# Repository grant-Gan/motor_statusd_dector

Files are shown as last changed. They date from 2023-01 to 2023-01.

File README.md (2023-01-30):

# 电机健康状态检测系统

该项目为基于ESP32 Arduino框架开发, ESP32通过热电偶与振动传感器检测电机四个点的震动状态以及温度判数据; 而后将数据上传致One Net云平台, 进行数据可视化显示与报警阈值的动态设置.

硬件连接图:
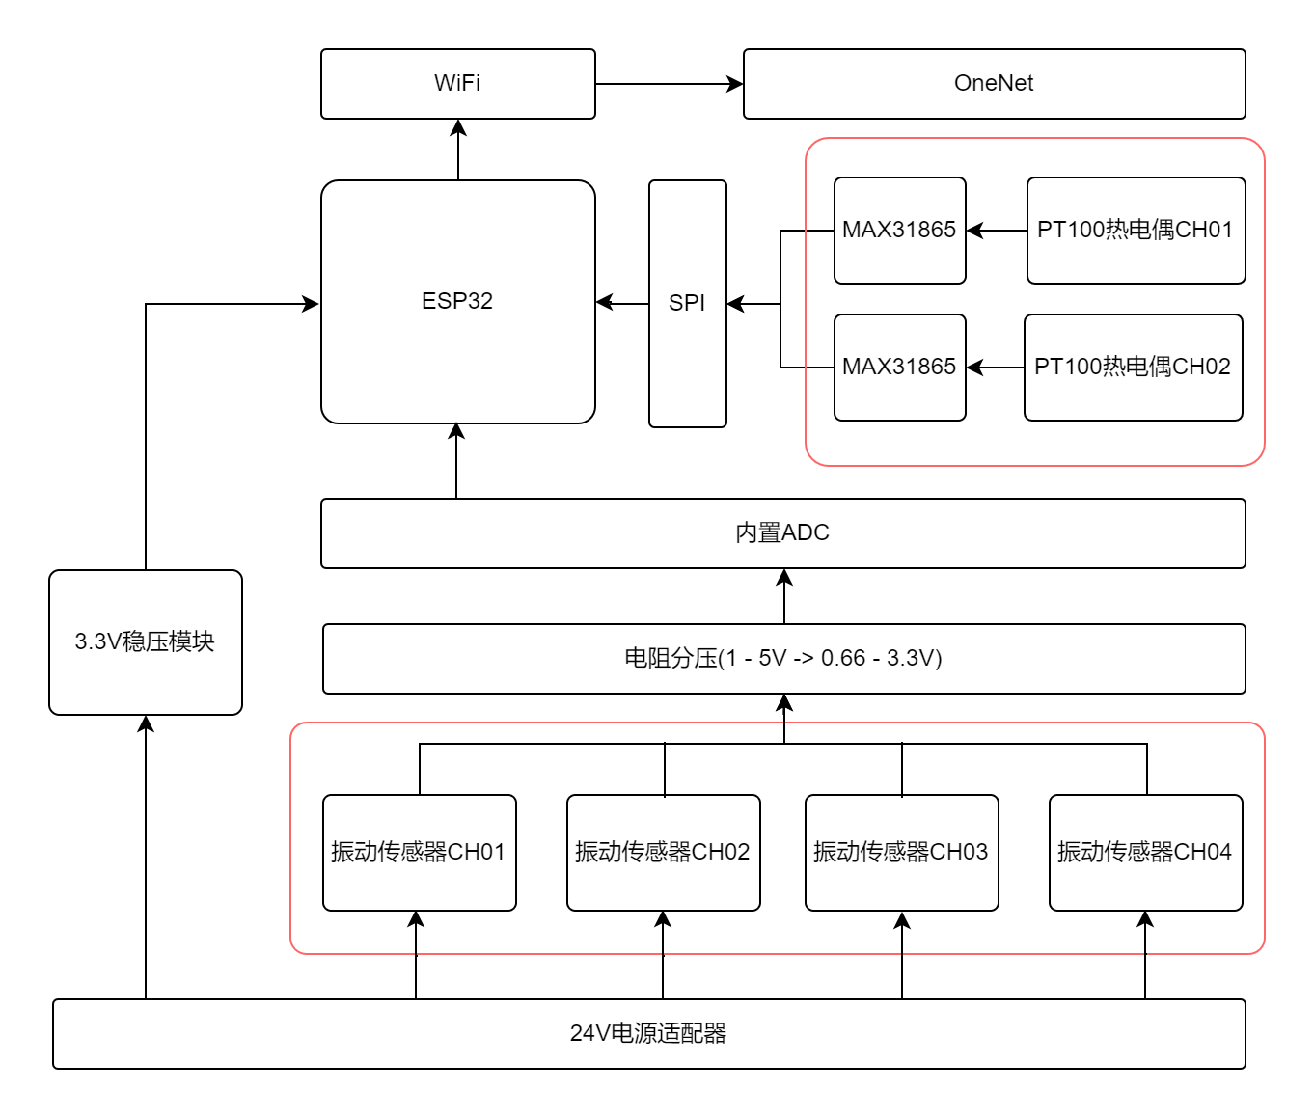
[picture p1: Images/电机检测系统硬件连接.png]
系统框架连接图


程序框图:
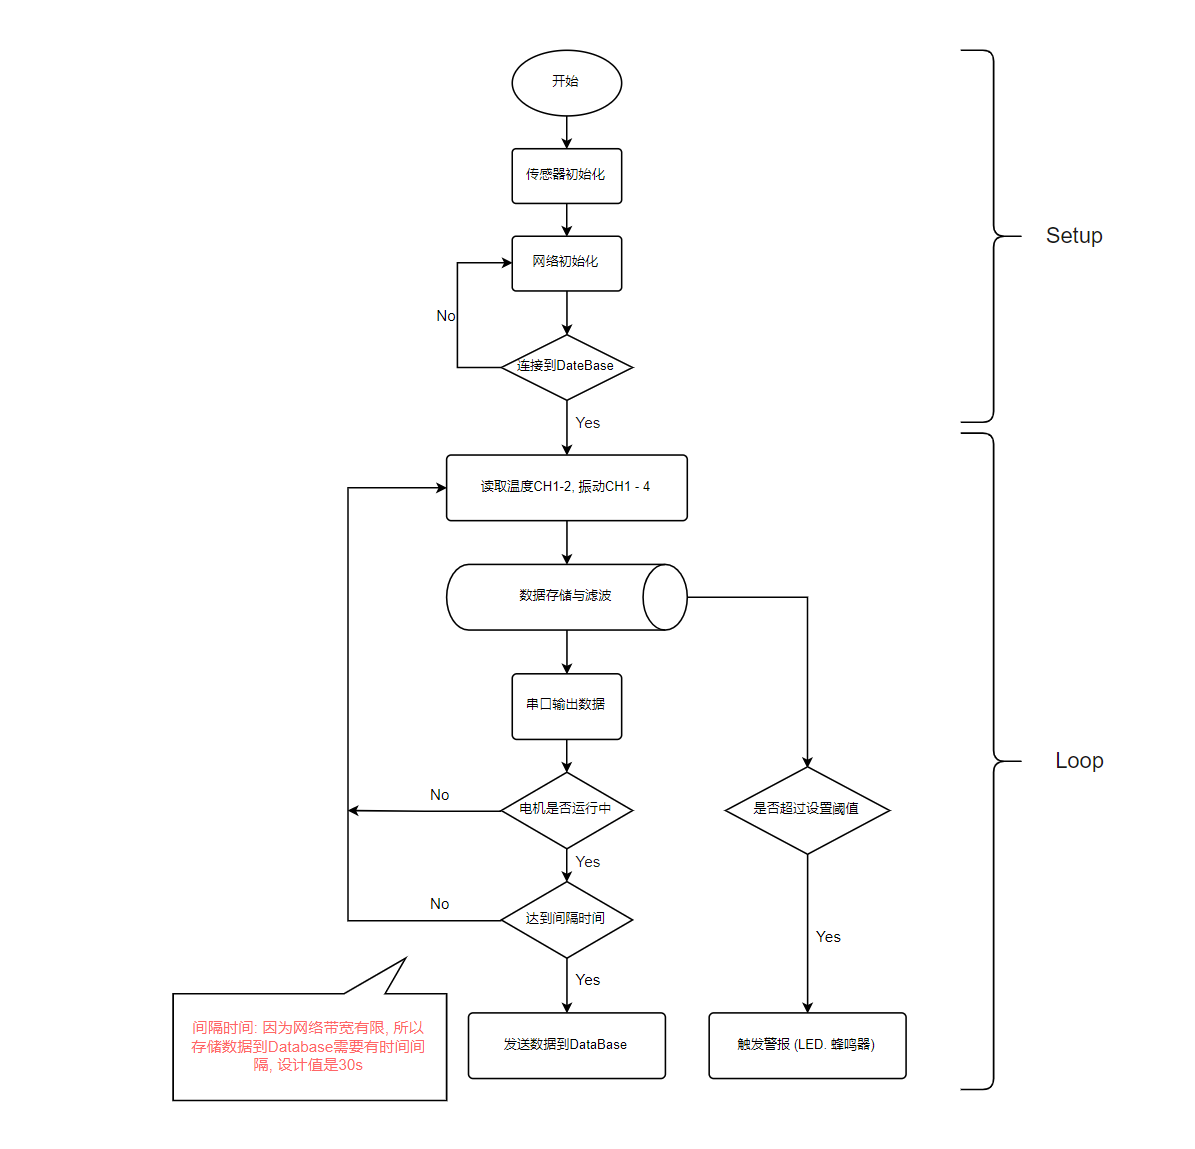
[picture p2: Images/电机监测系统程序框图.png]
程序框图


One Net数据可视化:
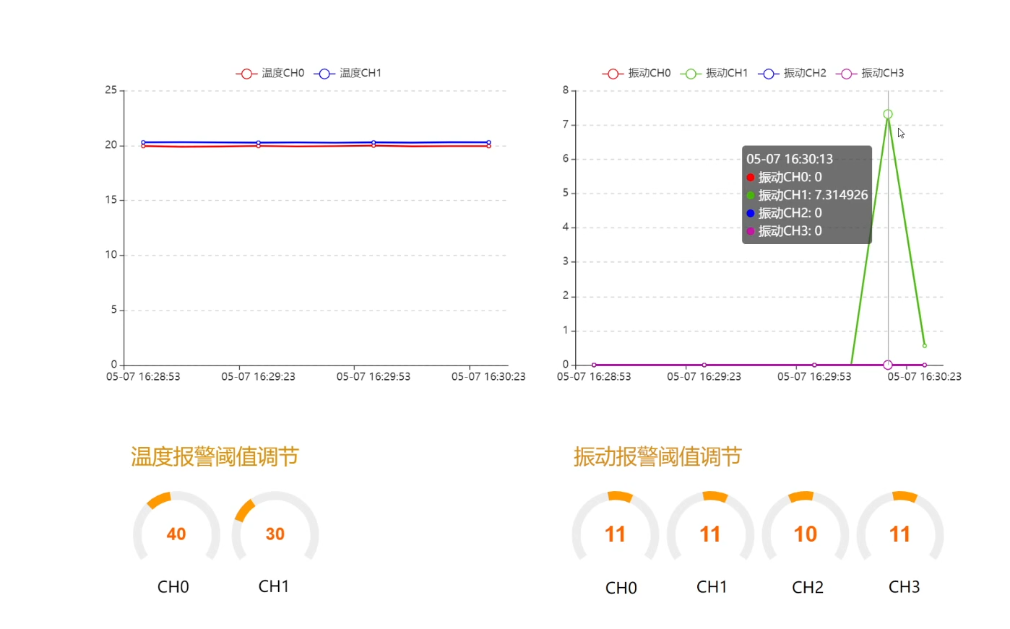
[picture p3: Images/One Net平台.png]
One Net平台预览


PCB 3D模型预览:
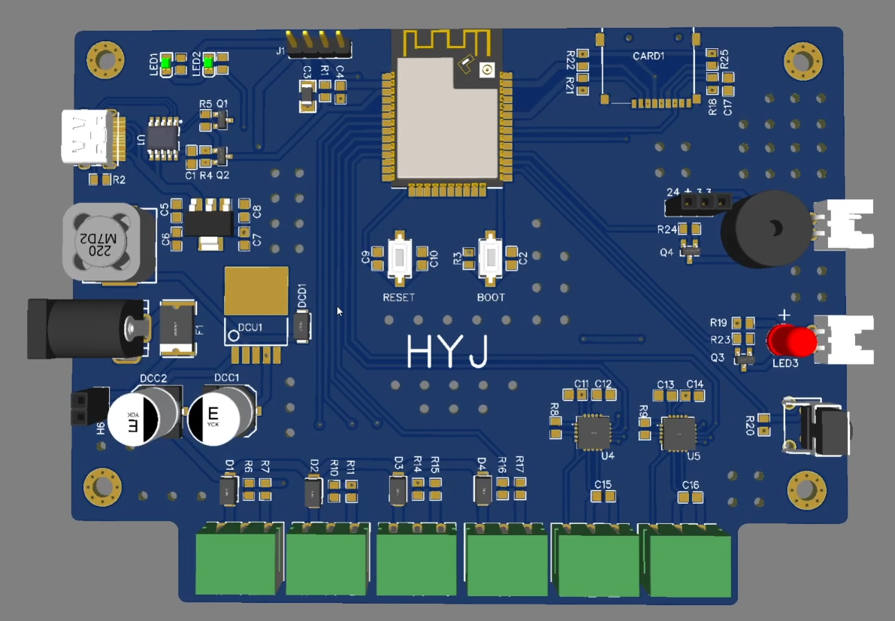
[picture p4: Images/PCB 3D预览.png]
PCB 3D模型预览


最终实物:
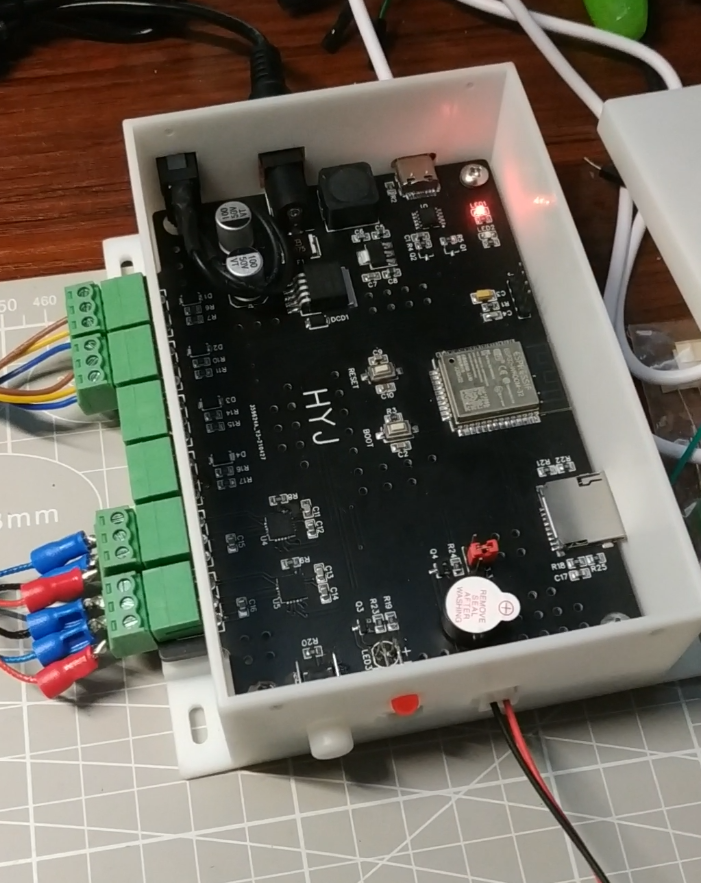
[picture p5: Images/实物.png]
最终实物


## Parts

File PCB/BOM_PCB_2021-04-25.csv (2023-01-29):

ID | Designator | Name | Footprint | Quantity | Manufacturer Part | Manufacturer | Supplier | Supplier Part | Price | JLCPCB SMD | Paste Type | EasyEDA
1 | BOOT,RESET | BOOT | KEY-SMD_2P-L6.2-W3.6-LS8.0 | 2 | K2-1107ST-A4SW-06 |  | LCSC | C118141 | 0.0423
2 | C1,C5,C7,C17 | 104 | C0805 | 4 |  |  | LCSC
3 | C3 | 100uF | 1206 | 1
4 | C6,C8 | 10uF | C0805 | 2 |  |  | LCSC
5 | C9 | 105 | C0805 | 1
6 | C2,C4,C10,C11,C12,C13,C14,C15,C16 | 104 | C0805 | 9
7 | CARD1 | TF-01A | TF-SMD_TF-01A | 1 | TF-01A | HRO | LCSC | C91145 | 1.1823
8 | CN1 | YKYB40-CH00 | CONN-TH_3P-P3.81_KF2EDGR-3.81-3P | 1 | KF2EDGR-3.81-3P | Cixi Kefa Elec | LCSC | C441183 | 0.318802 |  | expand
9 | CN2 | YKYB40-CH01 | CONN-TH_3P-P3.81_KF2EDGR-3.81-3P | 1 | KF2EDGR-3.81-3P | Cixi Kefa Elec | LCSC | C441183 | 0.318802 |  | expand
10 | CN3 | PT100-CH0 | CONN-TH_3P-P3.81_KF2EDGR-3.81-3P | 1 | KF2EDGR-3.81-3P | Cixi Kefa Elec | LCSC | C441183 | 0.318802 |  | expand
11 | CN4 | PT100-CH1 | CONN-TH_3P-P3.81_KF2EDGR-3.81-3P | 1 | KF2EDGR-3.81-3P | Cixi Kefa Elec | LCSC | C441183 | 0.318802 |  | expand
12 | CN5 | YKYB40-CH02 | CONN-TH_3P-P3.81_KF2EDGR-3.81-3P | 1 | KF2EDGR-3.81-3P | Cixi Kefa Elec | LCSC | C441183 | 0.318802 |  | expand
13 | CN6 | YKYB40-CH03 | CONN-TH_3P-P3.81_KF2EDGR-3.81-3P | 1 | KF2EDGR-3.81-3P | Cixi Kefa Elec | LCSC | C441183 | 0.318802 |  | expand
14 | D1,D2,D3,D4 | SS34 | SMAF | 4 | 1N4007W | BLUE ROCKET | LCSC | C328592 | 0.04999
15 | DC1 | DC005-2.0MM | DC-IN-TH_DC005 | 1 | DC005-2.0MM | SOFNG | LCSC | C111567 | 1
16 | DCC1,DCC2 | 100uF | SMD-8*10.5 | 2
17 | DCD1 | SS54 | SMAF | 1
18 | DCL1 | 330 | IND-SMD_L12.0-W12.0_CDRH127NP | 1
19 | DCU1 | LM2596-3.3 | LM2596 | 1 | ?
20 | F1 | TLC-LSMD050/50 | F2920 | 1 | TLC-LSMD050/50 | TLC Electronic | LCSC | C506870 | 0.562325
21 | H1,H2,H3,H4 | Hole-3mm-JK 孔 | HOLE-3MM | 4 | Hole-3mm
22 | H5 | HDR-F-2.54_1x3 | HDR-F-2.54_1X3 | 1 |  |  | LCSC | C146690 | 0.278
23 | H6 | PowerSwitch | HDR-F-2.54_1X2 | 1 |  |  | LCSC | C49661 | 0.162
24 | H7 | BUZZER | XH2.54-2AW | 1 |  |  | LCSC | C49661 | 0.162
25 | H8 | WAR_LED | XH2.54-2AW | 1 |  |  | LCSC | C49661 | 0.162
26 | J1 | 串口 | HDR-M-2.54_1X4 | 1 |  |  | LCSC | C124378 | 0.143949
27 | LED1,LED2 | LED-0805_R | LED0805-RD | 2 | 19-217/R6C-AL1M2VY/3T | EVERLIGHT(台湾亿光) | LCSC | C72044 | 0.081951
28 | LED3 | LED-TH-5mm_R | LED-TH_BD5.0_RED | 1 | 333-2SURD/S530-A3 | EVERLIGHT(台湾亿光) | LCSC | C87271 | 0.191428
29 | Q1,Q2 | S8050 | SOT-23-3_L2.9-W1.3-P1.90-LS2.4-BR | 2 | S8050 | FUXINSEMI | LCSC | C908252 | 0.058733 | Yes
30 | Q3,Q4 | 2N5551 | SOT-23-3_L2.9-W1.3-P1.90-LS2.4-TR | 2 | 2n3904S-RTK/PS | KEC | LCSC | C18536 | 0.071167 |  | SOT-23
31 | R1,R3 | 4.7k | R0805 | 2
32 | R2 | 5.1K | R0805 | 1 | AF0603FR-0710KL | YAGEO | LCSC | C144081 | 0.045
33 | R4,R5,R18,R21,R22,R25 | 10K | R0805 | 6 | TC0325F1002T5E | UniOhm | LCSC | C128781 | 0.0268 | Yes
34 | R6,R10,R11,R14,R15,R16,R17,R20 | 10k | R0805 | 8
35 | R7 | 10k 1% | R0805 | 1
36 | R8,R9 | 430 | R0805 | 2 | RMC06034.7K1%N | Tyohm | LCSC | C269713 | 0.015397
37 | R12,R13,R19,R23,R24 | 1k | R0805 | 5
38 | SG1 | BUZZER | BUZZER-12MM-NS | 1
39 | SW1 | 卧式按键开关 | 轻触按键开关卧式带支架 | 1
40 | U1 | CH340K | ESOP-10_L4.9-W3.9-P1.00-LS6.2-BL-EP | 1 | CH340K | WCH(Jiangsu Qin Heng) | LCSC | C968586 | 3.28
41 | U2 | AMS1117-3.3 | SOT-223 | 1 | AMS1117-3.3 | AMS | EasyEDA | C6186 | 0.728 |  |  | C6186
42 | U3 | ESP32-S | WIRELM-SMD_ESP32-S | 1 | ESP32-S | Ai-Thinker | LCSC | C277944 | 25.9
43 | U4,U5 | MAX31865ATP+ | QFN-20_L5.0-W5.0-P0.65-BL-EP | 2 | MAX31865ATP+ | Maxim Integrated | LCSC | C404011 | 36.7 |  | expand
44 | USB1 | TYPE C 16PIN | TYPE C 16P | 1 | TYPE-C16PIN | SHOU HAN | LCSC | C393939 | 0.78

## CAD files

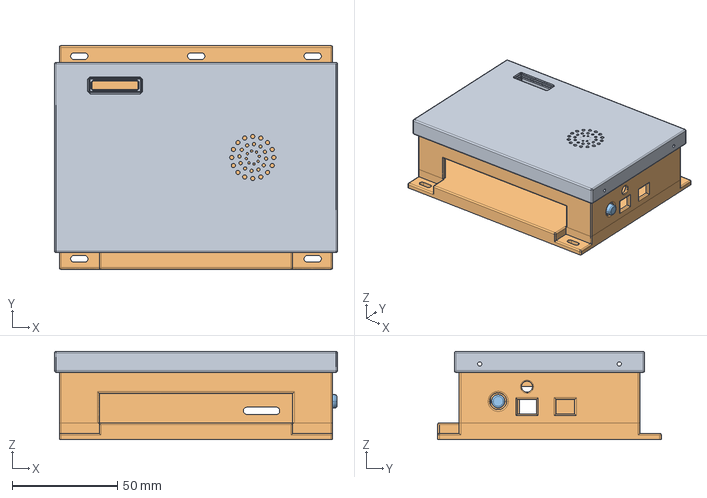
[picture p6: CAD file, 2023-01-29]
3DModel/3D模型.stp
134.6 x 106.4 x 42.0 mm

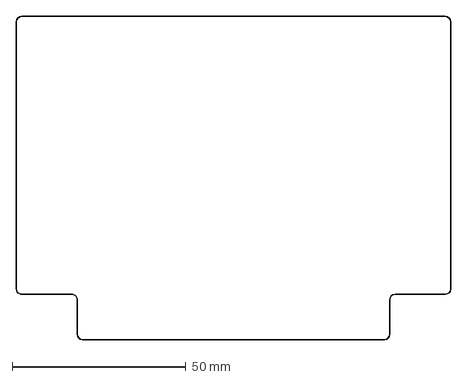
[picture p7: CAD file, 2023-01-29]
3DModel/pcb边缘.dxf
125.0 x 93.0 mm

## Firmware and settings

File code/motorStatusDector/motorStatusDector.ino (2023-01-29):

/*
  程序目的 : 实现传感器数据读取、超阈值监测、上传数据到云平台
  一、硬件材料
  1. 振动传感器 * 4 接在主板接口左侧四路接口上
  2. 温度传感器 * 2 接在主板接口右侧两路接口上
  3. 24v电源, 注意24V电源与USB接口不可同时供电
  4. SD卡
  二、预期效果
  1. 状态指示灯会先亮起, 大约七八秒以后熄灭, 之后每十秒闪烁一次
  2. 数据会被写入到SD卡
  3. 数据会被上传到OneNet平台
  4. 会从OneNet平台读取最新的阈值
  5. 当传感器的采集到的数据超过阈值以后, 会报警(红灯亮+蜂鸣器响)

  更新信息:
    更新日期: 2021/5/12/17:13
    更新内容:
      - 增加只有在电机运行时才会自动进行SD卡及oneNet端数据上传功能
      - 增加motor::getRunningStatus()方法

    更新日期: 2021/5/14/22:56
    更新内容:
      - 在数据写入和上传之前更新一次传感器数据
      - 将阈值一起写入CSV文件

    更新日期: 2021/5/18/18:46
    更新内容:
      - 修复超过阈值时写入表格数据错误问题   
*/

#include <Arduino.h>
#include <string>
#include <Adafruit_MAX31865.h>
#include <WiFi.h>
#include <HTTPClient.h>
#include <ArduinoJson.h>
#include <FS.h>
#include <SD.h>
#include <SPI.h>
#include <time.h>
#include <Ticker.h>

//定义温度传感器通道数量
#define TEMP_CH 2
//定义振动传感器通道数量
#define VIBRA_CH 4
//定义SD卡CS引脚
#define SDCARD_CS_PIN 21
//定义max31865传感器CS引脚
#define TEMP_CH0_PIN 26
#define TEMP_CH1_PIN 25
//定义振动传感器模拟输出引脚
#define VIBRA_CH0_PIN 34
#define VIBRA_CH1_PIN 35
#define VIBRA_CH2_PIN 32
#define VIBRA_CH3_PIN 33
//报警器引脚
#define WARNNER_LED_PIN 16
#define WARNNER_BUZZER_PIN 17
#define WARNNER_INTERRUPT_PIN 4
//状态指示灯引脚
#define STATUS_LED 2
//定义平均值滤波中温度的采样次数
//因考虑到max31865传输数字信号, 故该值可较小
#define TEMP_SAMP_COUNT 5

//定义振动信号滤波采样次数
//因该信号为模拟量传输, 故该值可较大
#define VIBRA_SAMP_COUNT 51

const char* SSID = "TEST";
const char* PWD = "20201234";

const String api_key = "ZH8lES5PNdvqTcO82bbYuQ6AHBU=";
const String device_id = "716081919";


class TempSensor {

  protected:
    Adafruit_MAX31865 thermo;
    // Rref电阻阻值选择, PT100 -> 430 PT1000 -> 4300
    const float RREF = 430.0;
    // The 'nominal' 0-degrees-C resistance of the sensor
    // 100.0 for PT100, 1000.0 for PT1000
    const float RNOMINAL = 100.0;

  public:

    TempSensor(int8_t spi_cs) : thermo(spi_cs) {
      //传递spi_cs值, 并且设置PT100为三线制
      thermo.begin(MAX31865_3WIRE);
    }

    float readData() {
      float temperture = thermo.temperature(RNOMINAL, RREF);
      //Serial.print("temperature = \t"); Serial.println(temperture);

      return temperture;
    }

    // 检查检测温度是否有错误
    // 错误返回true, 否则返回flase
    bool checkFault() {
      uint8_t fault = thermo.readFault();

      if (fault) {
        Serial.print("Fault 0x"); Serial.println(fault, HEX);
        if (fault & MAX31865_FAULT_HIGHTHRESH) {
          Serial.println("RTD High Threshold");
        }
        if (fault & MAX31865_FAULT_LOWTHRESH) {
          Serial.println("RTD Low Threshold");
        }
        if (fault & MAX31865_FAULT_REFINLOW) {
          Serial.println("REFIN- > 0.85 x Bias");
        }
        if (fault & MAX31865_FAULT_REFINHIGH) {
          Serial.println("REFIN- < 0.85 x Bias - FORCE- open");
        }
        if (fault & MAX31865_FAULT_RTDINLOW) {
          Serial.println("RTDIN- < 0.85 x Bias - FORCE- open");
        }
        if (fault & MAX31865_FAULT_OVUV) {
          Serial.println("Under/Over voltage");
        }
        thermo.clearFault();
        return true;
      }
      else {
        return false;
      }
    }

};

class Motor {

  public:
    enum SenorChEnum
    {
      CH0 = 0,
      CH1,
      CH2,
      CH3
    };

    //温度和振动烈度的报警阈值, 为方便访问, 使用 public
    uint16_t tempThresholdCh[TEMP_CH] = { 100 };
    uint16_t vibraThresholdCh[VIBRA_CH] = { 10 };

    bool tempExceedFlagCh[TEMP_CH] = { false };
    bool vibraExceedFlagCh[VIBRA_CH] = { false };
  protected:

    TempSensor pt100Ch[TEMP_CH] = {
      TempSensor(TEMP_CH0_PIN),
      TempSensor(TEMP_CH1_PIN)
    };
    float tempCh[TEMP_CH] = { 0.0 };		//电机温度两通道
    float vibraCh[VIBRA_CH] = { 0.0 };		//电机振动烈度四通道
    bool runningStatus = false;
  public:
    //检查电机的运行状态, 运行中返回false, 否则返回true;
    bool getRunningStatus() {
      if ( (vibraCh[0] + vibraCh[1] + vibraCh[2] + vibraCh[3]) <= 0.01) {
        runningStatus = false;
        return false;
      }
      else {
        runningStatus = true;
        return true;
      }
    }
    //检查温度和振动的每一个通道, 如果有超过值, 则vibraExceedFlagChx设为true
    //并且方法返回true
    bool checkSenorExceed() {

      bool exceed = false;

      for (uint16_t i = 0; i < TEMP_CH; i++) {
        if (tempCh[i] >= tempThresholdCh[i]) {
          exceed = true;
          tempExceedFlagCh[i] = true;
        }
        else
          tempExceedFlagCh[i] = false;
      }
      for (uint16_t i = 0; i < VIBRA_CH; i++) {
        if (vibraCh[i] >= vibraThresholdCh[i]) {
          exceed = true;
          vibraExceedFlagCh[i] = true;
        }
        else
          vibraExceedFlagCh[i] = false;
      }
      return exceed;
    }

    //获取单通道温度值, 注意:该函数并不会更新数据, 只是单纯地返回上一次的读取值
    float getTempChx(SenorChEnum chx) {
      switch (chx)
      {
        case CH0 : return tempCh[CH0]; break;
        case CH1 : return tempCh[CH1]; break;
        default:
          Serial.println("Invalid channal ! ");
          break;
      }
    }

    //获取单通道振动值, 注意:该函数并不会更新数据, 只是单纯地返回上一次的读取值
    float getVibraChx(SenorChEnum chx) {
      switch (chx)
      {
        case CH0: return vibraCh[CH0]; break;
        case CH1: return vibraCh[CH1]; break;
        case CH2: return vibraCh[CH2]; break;
        case CH3: return vibraCh[CH3]; break;
        default:
          Serial.println("Invalid channal ! ");
          break;
      }
    }
    //获取温度传感器的值 存储在tempBuffer里面
    //参数: tempBuffer数组变量, 长度必须大于温度传感器通道数
    //    array_size数组长度
    bool getTemp(float tempBuffer[], uint16_t array_size) {
      if (array_size < TEMP_CH) {
        Serial.print("temp buffer size so short");
        return false;
      }
      if (!updateTemp()) {
        Serial.print("get temperture error!");
        return false;
      }
      tempBuffer[0] = this->tempCh[0];
      tempBuffer[1] = this->tempCh[1];
      return true;
    }
    //获取振动传感器的值 存储在vibraBuffer里面
    //参数: vibraBuffer数组变量, 长度必须大于温度传感器通道数
    //    array_size数组长度
    bool getVibra(float vibraBuffer[], uint16_t array_size) {
      if (array_size < VIBRA_CH) {
        Serial.print("vibra Buffer size so short");
        return false;
      }

      if (!updateVibra()) {
        Serial.print("get vibration error!");
        return false;
      }
      for (uint8_t i = 0; i < VIBRA_CH; i++)
        vibraBuffer[i] = vibraCh[i];

      return true;
    }

    //更新振动传感器数据
    //
    bool updateVibra() {

      //定义二位数组用于存放ADC采集到的振动传感器电压
      uint16_t vibra_voltage[VIBRA_CH][VIBRA_SAMP_COUNT] = { 0 };
      //定义单通道数组, 用于存放振动传感器经过滤波后的值
      uint16_t vibra_vol_filter[VIBRA_CH] = { 0 };

      for (uint8_t i = 0; i < VIBRA_SAMP_COUNT; i++) {
        vibra_voltage[0][i] = analogRead(VIBRA_CH0_PIN);
        vibra_voltage[1][i] = analogRead(VIBRA_CH1_PIN);
        vibra_voltage[2][i] = analogRead(VIBRA_CH2_PIN);
        vibra_voltage[3][i] = analogRead(VIBRA_CH3_PIN);
        delay(1);
      }

      for (uint8_t i = 0; i < VIBRA_CH; i++) {

        //设置数据上下限, 这里的448 和2947 为仪表测量值, 不可变动
        limiterMinMax(vibra_voltage[i], VIBRA_SAMP_COUNT, 448, 2947);
        //对采样数据进行中位值滤波
        filterMedian(vibra_vol_filter[i], vibra_voltage[i], VIBRA_SAMP_COUNT);
        //通过公式将电压信号转换为振动信号, 结果存储在vibraCh[x]数组里面
        convertVibraFromVoltage(vibraCh[i], vibra_vol_filter[i]);
        //2.5V -> 2946.41875->2947
        //1v -> 1073.375 -> 1073
        //0.5V -> 448.2582 -> 448

      }
      return true;
    }
    //更新温度数据
    //成功返回 true; 失败返回false
    bool updateTemp() {
      float temp_ch0_buffer[TEMP_SAMP_COUNT] = { 0.0 };
      float temp_ch1_buffer[TEMP_SAMP_COUNT] = { 0.0 };

      uint8_t count = 0;    //采样次数
      unsigned long startTime = millis();
      while (count < TEMP_SAMP_COUNT) {
        //while循环超时检测
        if (millis() - startTime >= 1000) {
          Serial.print("get temperture timeout");
          return false;
        }
        //max31865最大采样间隔时间为21ms, 这里取采样间隔25ms
        if (millis() - startTime >= 25) {
          startTime = millis();
          temp_ch0_buffer[count] = pt100Ch[0].readData();
          temp_ch1_buffer[count] = pt100Ch[1].readData();

          if (pt100Ch[0].checkFault() || pt100Ch[1].checkFault())
            continue;
          else
            count += 1;
        }

      }
      //将temp_buffer里的数据经过平均值滤波以后传入到tempCh[0/1];
      filterAvarge(tempCh[0], temp_ch0_buffer, TEMP_SAMP_COUNT);
      filterAvarge(tempCh[1], temp_ch1_buffer, TEMP_SAMP_COUNT);
      return true;
    }

  private:
    //将振动传感器的电压信号转化为振动信号
    void convertVibraFromVoltage(float& target, const uint16_t& source) {
      //(x - in_min) * (out_max - out_min) / (in_max - in_min) + out_min;
      //将电压信号有效值进行线性缩放至0-20mm/s的范围, 这里的数值为测量值或给定值
      //不可以进行更改, 运算过程参考arduino库的map函数
      target = (source - 448.0) * (20.0 - 0.0) / (2947.0 - 448.0) + 0.0;

    }

    //平均值滤波, 针对温度
    void filterAvarge( float& target, const float source[], uint16_t array_size) {
      float filter_sum = 0;

      for ( uint8_t i = 0; i < array_size; i++) {
        filter_sum += source[i];
      }
      target = filter_sum / array_size;
    }

    //数值限幅器
    void limiterMinMax(uint16_t source[], uint16_t arraySize, uint16_t minVaule, uint16_t maxVaule) {

      for (uint16_t i = 0; i < arraySize; i++) {
        if (source[i] < minVaule)
          source[i] = minVaule;
        else if (source[i] > maxVaule)
          source[i] = maxVaule;
        else
          continue;
      }
    }

    //中位值滤波, 针对振动
    void filterMedian(uint16_t& target, uint16_t source[], uint16_t arraySize) {
      uint8_t i, j;
      uint16_t filterTemp;

      // 采样值从小到大排列（冒泡法）
      for (j = 0; j < arraySize - 1; j++) {
        for (i = 0; i < arraySize - 1 - j; i++) {
          if (source[i] > source[i + 1]) {
            filterTemp = source[i];
            source[i] = source[i + 1];
            source[i + 1] = filterTemp;
          }
        }
      }
      //返回中间值
      target = source[(arraySize - 1) / 2];
    }

};

//定义OneNet对象, 对上传数据和 下载数据进行操作
//依赖库为<arduinoJson>
class OneNet {

  protected:
    String apiKey;
    String deviceId;
    String apiUrl = "http://api.heclouds.com/devices/" + deviceId;

  public:
    OneNet(String devId, String aKey) :
      deviceId(devId),
      apiKey(aKey) {}
    //从服务器获取数据, 并将结果更新到Motor对象里
    //主要是用户设定的传感器报警阈值
    void getDataFromServer(Motor& motor) {
      if (WiFi.status() == WL_CONNECTED) {

        HTTPClient http;
        String postUrl = apiUrl + "/datastreams";
        String response;

        http.begin(postUrl);
        http.addHeader("api-key", apiKey);
        http.addHeader("Connection", "close");
        http.addHeader("Content-Type", "application/json");

        int httpResponseCode = http.GET();
        if (httpResponseCode > 0) {

          response = http.getString();

          Serial.println(httpResponseCode);
          //Serial.println(response);
        }
        else
          Serial.println("Error occurred while sending HTTP GET");

        StaticJsonDocument<2048> doc;

        ArduinoJson::deserializeJson(doc, response);
        JsonObject obj = doc.as<JsonObject>();

        uint16_t responeJsonCode = obj["errno"];

        if (responeJsonCode == 0) {
          //此处数字根据服务器传回的Json文件更改的数组顺序, 不可修改
          motor.vibraThresholdCh[3] = obj["data"][3]["current_value"];
          motor.vibraThresholdCh[2] = obj["data"][2]["current_value"];
          motor.vibraThresholdCh[0] = obj["data"][5]["current_value"];
          motor.vibraThresholdCh[1] = obj["data"][0]["current_value"];
          //Serial.println("Vibra threshold is : ");
          //Serial.print("\tch0 "); Serial.print(motor.vibraThresholdCh[0]);
          //Serial.print("\tch1 "); Serial.print(motor.vibraThresholdCh[1]);
          //Serial.print("\tch2 "); Serial.print(motor.vibraThresholdCh[2]);
          //Serial.println("\tch3 "); Serial.print(motor.vibraThresholdCh[3]);

          motor.tempThresholdCh[0] = obj["data"][1]["current_value"];
          motor.tempThresholdCh[1] = obj["data"][4]["current_value"];
          //Serial.println("Temp threshold is : ");
          //Serial.print("\tch0 "); Serial.print(motor.tempThresholdCh[0]);
          //Serial.println("\tch1 "); Serial.print(motor.tempThresholdCh[1]);
        }
        else
          Serial.println("Json get error!");

        http.end();

      }
    }
    //传递motor对象的数据到服务器端, 主要是温度和振动传感器的数字, 传递文件为Json文件
    void postDataToServer(Motor& motor) {

      if (WiFi.status() == WL_CONNECTED) {

        HTTPClient http;

        String jsonOutput;
        String postUrl = apiUrl + "/datapoints";

        float tempBuffer[TEMP_CH] = { 0.0 };
        float vibraBuffer[VIBRA_CH] = { 0.0 };

        motor.getTemp(tempBuffer, TEMP_CH);
        motor.getVibra(vibraBuffer, VIBRA_CH);

        //创建静态Json文档, 这里的384是通过软件计算得到的缓存大小, 不可以任意更改
        StaticJsonDocument<512> doc;

        JsonArray datastreams = doc.createNestedArray("datastreams");

        JsonObject datastreams_0 = datastreams.createNestedObject();
        datastreams_0["id"] = "motorTemp";

        JsonObject datastreams_0_datapoints_0_value = datastreams_0["datapoints"][0].createNestedObject("value");
        datastreams_0_datapoints_0_value["CH0"] = tempBuffer[0];
        datastreams_0_datapoints_0_value["CH1"] = tempBuffer[1];

        JsonObject datastreams_1 = datastreams.createNestedObject();
        datastreams_1["id"] = "motorVibra";

        JsonObject datastreams_1_datapoints_0_value = datastreams_1["datapoints"][0].createNestedObject("value");
        datastreams_1_datapoints_0_value["CH0"] = vibraBuffer[0];
        datastreams_1_datapoints_0_value["CH1"] = vibraBuffer[1];
        datastreams_1_datapoints_0_value["CH2"] = vibraBuffer[2];
        datastreams_1_datapoints_0_value["CH3"] = vibraBuffer[3];

        JsonObject datastreams_2 = datastreams.createNestedObject();
        datastreams_2["id"] = "ThresholdExceed";

        JsonObject datastreams_2_datapoints_0_value = datastreams_2["datapoints"][0].createNestedObject("value");
        datastreams_2_datapoints_0_value["TCH0"] = motor.tempExceedFlagCh[0];
        datastreams_2_datapoints_0_value["TCH1"] = motor.tempExceedFlagCh[1];
        datastreams_2_datapoints_0_value["VCH0"] = motor.vibraExceedFlagCh[0];
        datastreams_2_datapoints_0_value["VCH1"] = motor.vibraExceedFlagCh[1];
        datastreams_2_datapoints_0_value["VCH2"] = motor.vibraExceedFlagCh[2];
        datastreams_2_datapoints_0_value["VCH3"] = motor.vibraExceedFlagCh[3];
        //将Json文件字符串化并存储到jsonOutput中
        serializeJson(doc, jsonOutput);
        //String json =
        //  "{\"datastreams\": [{\"id\": \"test\",\"datapoints\": [{\"value\": 68}]}]}";

        http.begin(postUrl);
        http.addHeader("api-key", apiKey);
        http.addHeader("Connection", "close");
        http.addHeader("Content-Type", "application/json");

        int httpResponseCode = http.POST(jsonOutput);
        //httpResponseCode > 0则传递成功
        if (httpResponseCode > 0) {

          String response = http.getString();

          Serial.println(httpResponseCode);
          Serial.println(response);

        }
        else {

          Serial.println("Error occurred while sending HTTP POST");

        }

        http.end();   //关闭并清理http服务端
      }

    }


};

//定义SDCard对象, 用于存储数据到本地SD卡的操作
class SDCard {

  protected:
    uint8_t csPin;

  public:
    SDCard(uint8_t cs_pin)
      : csPin(cs_pin) {}

    //SD卡初始化
    bool begin() {
      if (!SD.begin(csPin)) {
        Serial.println("Card Mount Failed");
        return false;
      }
      uint8_t cardType = SD.cardType();

      if (cardType == CARD_NONE) {
        Serial.println("No SD card attached");
        return false;
      }
      //判断SD卡剩余容量, 如果容量>110MB这里会不让用(对于124Mb的内存卡而言)
      //如果以后更换内存更大的卡, 这里需要更改
      //但是目前来说128Mb的内存卡已经很够了
      if (SD.usedBytes() / (1024 * 1024) > 110) {
        Serial.println("Warning : Casd size so short! ");
        return false;
      }

    }
    //添加数据到特定的文件
    void appendFile(fs::FS& fs, const char* path, const char* message) {
      Serial.printf("Appending to file: %s\n", path);

      File file = fs.open(path, FILE_APPEND);
      if (!file) {
        Serial.println("Failed to open file for appending");
        return;
      }
      if (file.print(message)) {
        Serial.println("Message appended");
      }
      else {
        Serial.println("Append failed");
      }
      file.close();
    }
    //添加传感器数据到SD卡
    void appendSenorDataToSD(Motor& motor, struct tm& tmstruct, const char* path) {

      //更新最新的写入时间
      getLocalTime(&tmstruct);
      String str = "block";

      //Temp_ch0 :,13.20,Exceed :, no,Temp_ch1 :, 13.20,Exceed :,no,Vibra_ch0 :,13.20,Exceed :,no,Vibra_ch1 :,13.20,Exceed :,no,....
      char buffer[1024] = {};
      //对数据进行组包后存放在buffer里方便写入
      sprintf(buffer,
              "Temp_ch0 :, %.2f,Exceed :, %s,Temp_ch1 :, %.2f,Exceed :, %s,"\
              "Vibra_ch0 :, %.2f,Exceed :, %s,Vibra_ch1 :, %.2f,Exceed :, %s,Vibra_ch2 :, %.2f,Exceed :, %s,Vibra_ch3 :, %.2f,Exceed :, %s,"\
              // "Threshold value,%d,%d,%d,%d,%d,%d"
              "%d-%02d-%02d %02d:%02d:%02d\n",
              motor.getTempChx(motor.CH0), motor.tempExceedFlagCh[motor.CH0] ? "yes" : "no",
              motor.getTempChx(motor.CH1), motor.tempExceedFlagCh[motor.CH1] ? "yes" : "no",
              motor.getVibraChx(motor.CH0), motor.vibraExceedFlagCh[motor.CH0] ? "yes" : "no",
              motor.getVibraChx(motor.CH1), motor.vibraExceedFlagCh[motor.CH1] ? "yes" : "no",
              motor.getVibraChx(motor.CH2), motor.vibraExceedFlagCh[motor.CH2] ? "yes" : "no",
              motor.getVibraChx(motor.CH3), motor.vibraExceedFlagCh[motor.CH3] ? "yes" : "no",
              // motor.tempThresholdCh[motor.CH0], motor.tempThresholdCh[motor.CH1], 
              // motor.vibraThresholdCh[motor.CH0], motor.vibraThresholdCh[motor.CH1], motor.vibraThresholdCh[motor.CH2], motor.vibraThresholdCh[motor.CH3], 
              (tmstruct.tm_year) + 1900, (tmstruct.tm_mon) + 1, tmstruct.tm_mday, tmstruct.tm_hour, tmstruct.tm_min, tmstruct.tm_sec);

      appendFile(SD, path, buffer);
      //结果写入的只有最后一行的时间 : 2021-xx-xx-xx xx:xx:xx

    }

};

//定义警报器对象用于处理传感器数值超过阈值时的警报
class Warnner {

  private:

    bool warnnerStatus = false;

  public:
    //构造函数对对象进行初始化
    Warnner() {
      pinMode(WARNNER_LED_PIN, OUTPUT);
      pinMode(WARNNER_BUZZER_PIN, OUTPUT);

      digitalWrite(WARNNER_LED_PIN, LOW);
      digitalWrite(WARNNER_BUZZER_PIN, LOW);
    }

    bool getWannerStatus() {
      return warnnerStatus;
    }
    //设置警报器是是否工作
    //参数status值为 true(打卡) 或 false(关闭)
    void setWanner(bool status) {
      //异或判断设定值与当前值是否相等
      if (warnnerStatus ^ status) {
        digitalWrite(WARNNER_LED_PIN, status);
        digitalWrite(WARNNER_BUZZER_PIN, status);
        warnnerStatus = status;
      }

    }
};

Motor motor;
Warnner wanner;
SDCard sdCard = SDCard(SDCARD_CS_PIN);
//OneNet传参为用户id和API_KEY
OneNet onenet = OneNet(device_id, api_key);
//创建两个时间任务调度器, 方便实现任务的定时执行
Ticker timCounterPer_1s, timCounterPer_10s;

//创建tm结构体, 用于保存时间数据
struct tm tmstruct;
//定时器达到标志
uint8_t TimeFlag_1s = 0;
uint8_t TimeFlag_10s = 0;
//阈值溢位标志
bool globalExceedFlag = false;
bool localExceedFlag = false;
//按键中断函数, 如果警报开启就立刻关闭警报
void IRAM_ATTR keyInterprrput() {
  // keyCount++;
  wanner.setWanner(false);
}
//定时任务, 定时标志位自加
void handleTimer_1s() {
  TimeFlag_1s++;
}
void handleTimer_10s() {
  TimeFlag_10s++;
}

void setup() {
  //配置工作状态指示灯
  pinMode(STATUS_LED, OUTPUT);
  digitalWrite(STATUS_LED, LOW);
  //打开串口输出
  Serial.begin(115200);
  //wifi mode设置为STA
  WiFi.mode(WIFI_MODE_STA);
  WiFi.begin(SSID, PWD);
  //等待wifi连接上
  while (WiFi.status() != WL_CONNECTED) {
    delay(500);
    Serial.print(".");
  }
  //从服务器获取当前时间戳, 并且存入tm结构体
  configTime(3600 * 8, 0, "time.nist.gov", "0.pool.ntp.org", "1.pool.ntp.org");
  getLocalTime(&tmstruct, 5000);
  //从oneNet服务器获取传感器阈值数据
  onenet.getDataFromServer(motor);
  sdCard.begin();
  //设置报警停止按键中断: 下降沿中断
  pinMode(WARNNER_INTERRUPT_PIN, INPUT);
  attachInterrupt(digitalPinToInterrupt(WARNNER_INTERRUPT_PIN), keyInterprrput, FALLING);
  //定时器配置
  //timCounterPer_1s.attachms(500, handleTimer_1s);
  timCounterPer_1s.attach(1, handleTimer_1s);
  timCounterPer_10s.attach(10, handleTimer_10s);
  //阻塞5S 等待所有配置完成
  delay(5000);
  //状态指示灯关闭, 程序开始工作
  digitalWrite(STATUS_LED, HIGH);
}

void loop() {
  //如果1S的定时任务到时间就执行相应的功能
  //这里的功能包括更新传感器数据和超阈值报警
  if (TimeFlag_1s > 0) {
    TimeFlag_1s = 0;
    motor.updateTemp();
    motor.updateVibra();
    //如果溢位标志为true则发送一次更新数据请求
    if (globalExceedFlag = motor.checkSenorExceed()) {
      wanner.setWanner(true);
      if(globalExceedFlag != localExceedFlag){
        localExceedFlag = globalExceedFlag;
         onenet.postDataToServer(motor);
      }
    }

  }
  //如果10S的定时任务到时间就执行相应的功能
  //这里的功能包括 :
  //1. 上传和下载系统数据到onenet
  //2. 存储数据到SD卡
  if (TimeFlag_10s > 0) {
    TimeFlag_10s = 0;
    //如果电机处于启动状态则继续运行
    if (motor.getRunningStatus()) {
      digitalWrite(STATUS_LED, LOW);
      //存储数据到SD卡
      sdCard.appendSenorDataToSD(motor, tmstruct, "/SenorData.CSV");
      //发送数据到onenet服务器
      onenet.postDataToServer(motor);
      //从onenet获取最新的阈值设定
      onenet.getDataFromServer(motor);
      digitalWrite(STATUS_LED, HIGH);
    }
  }

}

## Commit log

2023-01-29 首次提交
    [3D模型.stp, BOM_PCB_2021-04-25.csv, pcb边缘.dxf]
2023-01-30 添加了Readme内容
